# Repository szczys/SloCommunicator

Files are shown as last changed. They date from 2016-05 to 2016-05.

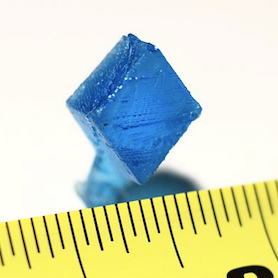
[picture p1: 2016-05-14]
board/peachy.png

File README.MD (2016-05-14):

SloCommunicator
======

Screen with Know and Home Etched Board

Communicator watch built for 2016 Bring-a-Hack (end of Bay Area Maker Faire Weekend).

This is based on the stalled [SloJak](https://github.com/szczys/SloJak) project. It is a 128x64 OLED screen with a rotary encoder and two buttons (actually 3 with encoder click but that's not designed into the board artwork).

Two things prevent this watch from communicating: I would need a second one to communicate with, and I didn't include the 900 MHz radio module in the design. This is just a quick and dirty built.

To make up for the lack of actual communications I will write KnobSnake, a classic game of snake that's played only by spinning the rotary encoder knob.

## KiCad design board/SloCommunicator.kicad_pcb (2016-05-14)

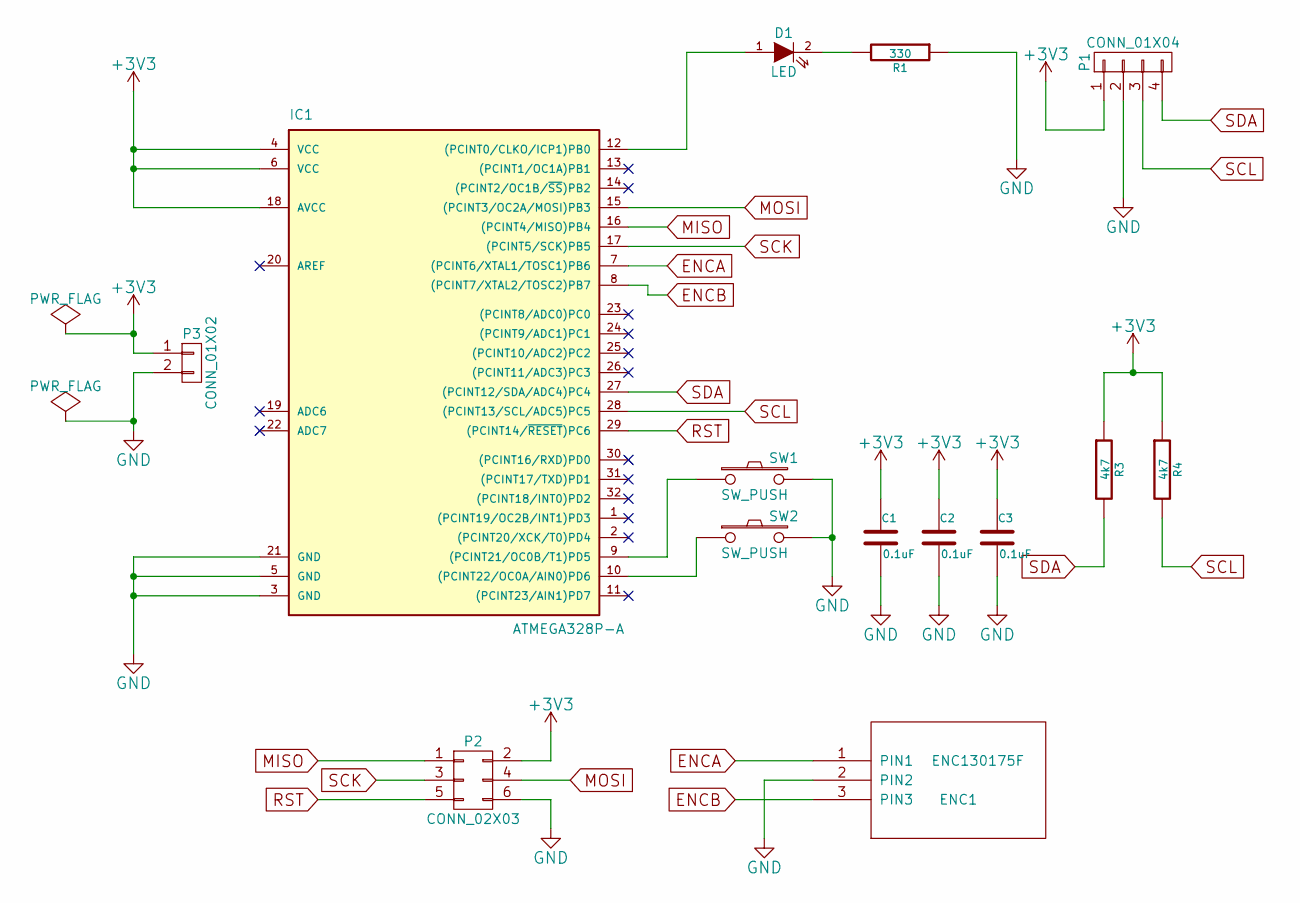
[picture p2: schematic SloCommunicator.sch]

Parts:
C1, C2, C3: 0.1uF; C_0805
D1: LED; LED_0805
ENC1: ENC130175F; enc130175f
IC1: ATMEGA328P-A; TQFP-32_7x7mm_Pitch0.8mm
P1: CONN_01X04; Pin_Header_Straight_1x04
P2: CONN_02X03; Pin_Header_Straight_2x03
P3: CONN_01X02; Pin_Header_Straight_1x02
R1: 330; R_0805
R3, R4: 4k7; R_0805
SW1, SW2: SW_PUSH; TACT_SMALL

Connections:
+3V3: C1.1, C2.1, C3.1, IC1.4 (VCC), IC1.6 (VCC), IC1.18 (AVCC), P1.1, P2.2, P3.1, R3.1, R4.1
ENCA: ENC1.1 (PIN1), IC1.7 ((PCINT6/XTAL1/TOSC1)PB6)
ENCB: ENC1.3 (PIN3), IC1.8 ((PCINT7/XTAL2/TOSC2)PB7)
GND: C1.2, C2.2, C3.2, ENC1.2 (PIN2), IC1.3 (GND), IC1.5 (GND), IC1.21 (GND), P1.2, P2.6, P3.2, R1.1, SW1.2, SW2.2
MISO: IC1.16 ((PCINT4/MISO)PB4), P2.1
MOSI: IC1.15 ((PCINT3/OC2A/MOSI)PB3), P2.4
unnamed: D1.1 (A), IC1.12 ((PCINT0/CLKO/ICP1)PB0)
unnamed: D1.2 (K), R1.2
unnamed: IC1.9 ((PCINT21/OC0B/T1)PD5), SW1.1
unnamed: IC1.10 ((PCINT22/OC0A/AIN0)PD6), SW2.1
RST: IC1.29 ((PCINT14/~RESET~)PC6), P2.5
SCK: IC1.17 ((PCINT5/SCK)PB5), P2.3
SCL: IC1.28 ((PCINT13/SCL/ADC5)PC5), P1.3, R4.2
SDA: IC1.27 ((PCINT12/SDA/ADC4)PC4), P1.4, R3.2

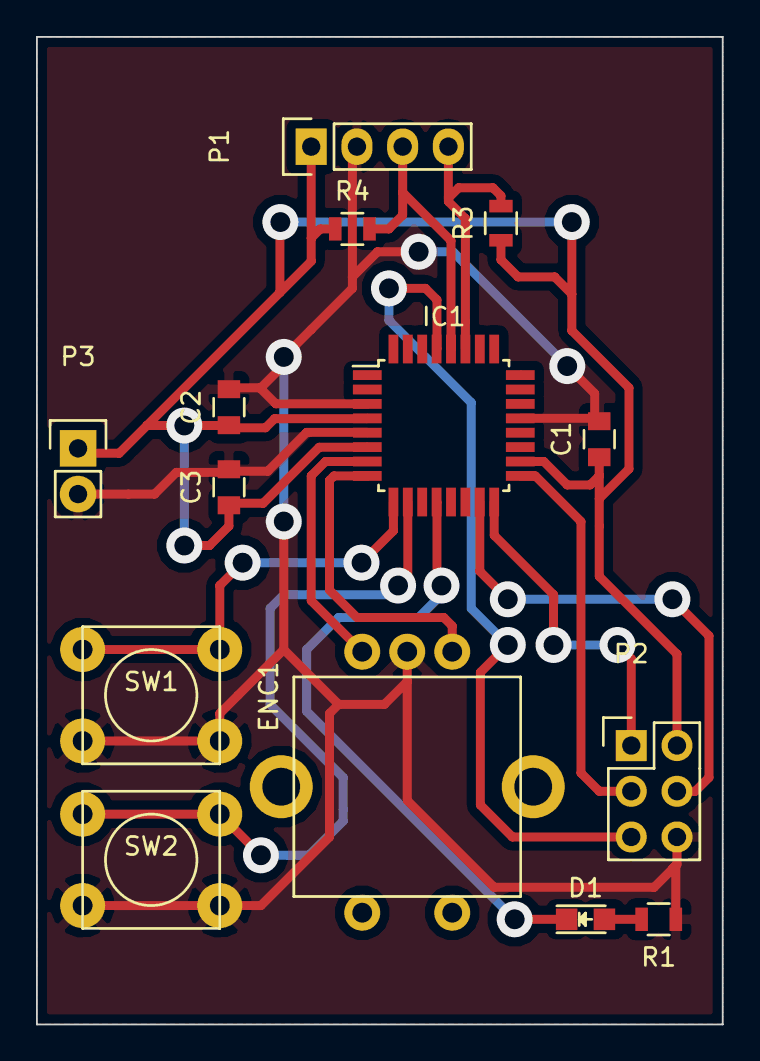
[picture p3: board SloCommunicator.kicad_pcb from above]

Board: 2 copper layers, 38.1 x 54.9 mm, 14 parts (0 on the bottom side), 14 nets.

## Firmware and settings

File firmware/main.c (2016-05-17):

/********************************
* SloJak                    	*
* MIT License               	*
* Copyright 2015 - Mike Szczys  *
* http://jumptuck.com 	    	*
*				                *
********************************/

#define F_CPU 8000000

#include <avr/io.h>
#include <avr/interrupt.h>
#include <avr/pgmspace.h>
#include <util/delay.h>

#include "menu.h"
#include "oledControl.h"
#include "game.h"


/************** Setup a rotary encoder ********************/
/* Atmega168 */
/* encoder port */
#define ENC_CTL	DDRB	//encoder port control
#define ENC_WR	PORTB	//encoder port write
#define ENC_RD	PINB	//encoder port read
#define ENC_A 6
#define ENC_B 7

volatile int8_t knobChange = 0;

/************** Setup input buttons *********************/
#define BUT_DDR     DDRD
#define BUT_PORT    PORTD
#define BUT_PIN     PIND
#define BUT_LEFT    (1<<PD5)
#define BUT_SEL     (1<<PD6)
#define BUT_MSK     (BUT_LEFT | BUT_SEL)

//Debounce
unsigned char debounce_cnt = 0;
volatile unsigned char key_press;
unsigned char key_state;

uint8_t goLeft = 0;
uint8_t goSel = 0;

uint8_t message[140] = "HELLOWORLDHELLOWORLDHELLOWORLDHELLOWORLDHELLOWORLDHELLOWORLDHELLOWORLD\0";

/**************** Prototypes *************************************/
unsigned char get_key_press(unsigned char key_mask);
void init_IO(void);
void init_interrupts(void);
int main(void);
/**************** End Prototypes *********************************/

/*********************
* Debounce Functions *
*********************/

unsigned char get_key_press(unsigned char key_mask)
{
  cli();               // read and clear atomic !
  key_mask &= key_press;                        // read key(s)
  key_press ^= key_mask;                        // clear key(s)
  sei();
  return key_mask;
}

void init_IO(void){
    //Rotary Encoder
    ENC_CTL &= ~(1<<ENC_A | 1<<ENC_B);
    ENC_WR |= 1<<ENC_A | 1<<ENC_B;

    //Buttons
    BUT_DDR &= ~(BUT_LEFT | BUT_SEL);      //Set as input
    BUT_PORT |= BUT_LEFT | BUT_SEL;      //Enable pull-up
}

void init_interrupts(void) {
    //Pin change interrupts for the rotary encoder
    PCICR |= 1<<PCIE0;      //enable PCINT0_vect  (PCINT0..7 pins)
    PCMSK0 |= 1<<PCINT6;    //interrupt on PCINT6 pin
    PCMSK0 |= 1<<PCINT7;    //interrupt on PCINT7 pin

    //Timer overflow for debounce and systick
    TCCR0B |= 1<<CS02 | 1<<CS00;		//Divide by 1024
    TIMSK0 |= 1<<TOIE0;			//enable timer overflow interrupt

    sei();
}

int main(void)
{
    init_IO();
    init_interrupts();
    oledInit();
    _delay_ms(200);

    oledSetCursor(cursX, cursY);
    putChar(66,1);
    advanceCursor(6);

    compose();

    initMenu();

    while(1)
    {
        if (get_key_press(BUT_SEL))
        {
            //Lookup and execute action
            doSelect[optionIndex]();
        }

        if (get_key_press(BUT_LEFT))
        {
            doBack();
        }

        if (knobChange) {
            if (knobChange > 0) {
                knobLeft();
            }
            else {
                knobRight();
            }
            knobChange = 0;
        }
        
        if (game_running && move_tick) {
            serviceGame();
            move_tick = 0;
        }
    }
}

ISR(PCINT0_vect) {
    /* Encoder service code is from Circuits@Home */
    /* https://www.circuitsathome.com/mcu/rotary-encoder-interrupt-service-routine-for-avr-micros */

    static uint8_t old_AB = 3;  //lookup table index
    static int8_t encval = 0;   //encoder value
    static const int8_t enc_states [] PROGMEM = {0,-1,1,0,1,0,0,-1,-1,0,0,1,0,1,-1,0};  //encoder lookup table

    old_AB <<=2;  //remember previous state
    old_AB |= ((ENC_RD>>6) & 0x03 ); //Shift magic to get PB6 and PB7 to LSB
    encval += pgm_read_byte(&(enc_states[( old_AB & 0x0f )]));
    /* post "Navigation forward/reverse" event */
    if( encval < -3 ) {  //four steps forward
        knobChange = -1;
        encval = 0;
    }
    else if( encval > 3  ) {  //four steps backwards
        knobChange = 1;
        encval = 0;
    }
}

ISR(TIMER0_OVF_vect) {
    static unsigned char ct0, ct1;
    unsigned char i;

    TCNT0 = (unsigned char)(signed short)-(F_CPU / 1024 * 10e-3 + 0.5);   // preload for 10ms

    i = key_state ^ ~BUT_PIN;    // key changed ?
    ct0 = ~( ct0 & i );          // reset or count ct0
    ct1 = ct0 ^ (ct1 & i);       // reset or count ct1
    i &= ct0 & ct1;              // count until roll over ?
    key_state ^= i;              // then toggle debounced state
    key_press |= key_state & i;  // 0->1: key press detect
    
    static uint8_t delayCount = STD_DELAY/10;   //This is a red herring. delayCount should be exposed to game.c
    
    if (++timingDelay >= delayCount) {
        timingDelay = 0;
        ++move_tick;
    }
}

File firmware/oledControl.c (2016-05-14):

#include "oledControl.h"
#include "font5x8.h"
#include <avr/pgmspace.h>

void oledInit(void) {
    cursX = 1;
    cursY = 0;

    i2c_init();

    oledWriteCmd(OLED_CMD_DISPLAY_OFF);
    oledWriteCmd(0xD5); //clkdiv
    oledWriteCmd(0x80);
    oledWriteCmd(0xA8); //multiplex
    oledWriteCmd(0x3F);
    oledWriteCmd(0xD3); //displayoffet
    oledWriteCmd(0x00);
    oledWriteCmd(0x40); //displayStartLine
    oledWriteCmd(0x8D);
    oledWriteCmd(0x14);
    oledWriteCmd(0x20);
    oledWriteCmd(PAGE_ADDRESSING);
    oledWriteCmd(0xA1); //segremap 0x01
    oledWriteCmd(0xC8); //comscandec
    oledWriteCmd(0xDA);
    oledWriteCmd(0x12);
    oledWriteCmd(0x81);
    oledWriteCmd(0xCF);
    oledWriteCmd(0xD9);
    oledWriteCmd(0xF1);
    oledWriteCmd(0xDB);
    oledWriteCmd(0x40);

    oledWriteCmd(0x26);

    oledWriteCmd(0x00);
    oledWriteCmd(0x05);
    oledWriteCmd(0x00);
    oledWriteCmd(0x07);

    oledWriteCmd(0x2F);
    //oledWriteCmd(0x2E);

    //oledWriteCmd(0x26);
    oledWriteCmd(OLED_CMD_DISPLAY_ON);
    oledWriteCmd(OLED_CMD_NORMAL_DISPLAY);

/*
    i2c_start_wait(OLED_ADDRESS);
    i2c_write(OLED_COMMAND_MODE);
    i2c_write(0x26);
    i2c_write(0x00);
    i2c_write(0x00);
    i2c_write(0x00);
    i2c_write(0x00);
    i2c_write(0x00);
    i2c_write(0xFF);
    i2c_stop();
*/
    oledClearScreen(1);
}

void oledWriteCmd(uint8_t cmd) {
    i2c_start_wait(OLED_ADDRESS+I2C_WRITE);
    i2c_write(OLED_COMMAND_MODE);
    i2c_write(cmd);
    i2c_stop();
}

void oledWriteData(uint8_t data) {
    i2c_start_wait(OLED_ADDRESS+I2C_WRITE);
    i2c_write(OLED_DATA_MODE);
    i2c_write(data);
    i2c_stop();
}

void oledSetCursor(uint8_t col, uint8_t page) {
    col += 2;   //Display off by 2 columns for some reason
    //Page
    oledWriteCmd(0xB0 + page);
    //Column
    oledWriteCmd(0x0F & col);
    oledWriteCmd(0x10 + (col>>4));
}

void oledClearScreen(uint8_t black) {
    uint8_t value = 0xFF;
    if (black) { value = 0x00; }
    for (uint8_t page=0; page<8; page++) {
        oledWriteCmd(0xB0 + page);
        oledWriteCmd(0x00);
        oledWriteCmd(0x10);
        i2c_stop();

        i2c_start_wait(OLED_ADDRESS);
        i2c_write(OLED_DATA_MODE);
        for (uint8_t col=0; col<128; col++) {
            oledWriteData(value);
        }
        i2c_stop();
    }
}

void putChar(uint8_t charIdx, uint8_t inverted) {
    uint8_t invertMask = 0x00;
    if (inverted) { invertMask = 0xFF; }
    for (uint8_t col = 0; col < 5; col++) {
        oledWriteData((getFont(charIdx,col))^invertMask);
    }
    oledWriteData(invertMask);    //Space after each letter
}

char getFont(uint8_t charIdx, uint8_t column)
{
    return pgm_read_byte(font5x8+((charIdx-32)*5)+column);
}

void putString(int16_t x, int16_t y, char *msg, uint8_t inverted) {
    const uint8_t charWidth = 6;
    const uint8_t charHeight = 1;

    //Find str length
    uint8_t i;
    for (i=0; i<141; i++) {
        if (msg[i] == 0) {
            if (i == 0) { return; } //zero len string
            else { break; }
        }
    }
    uint16_t colPosition;
    uint16_t rowPosition;
    for (uint8_t j=0; j<i; j++) {
        colPosition = x+(charWidth*j);
        rowPosition = y;

        //Linewrap
        if (colPosition+charWidth >= SCREENX) {
            uint8_t charPerRow = (SCREENX/charWidth);
            uint8_t charPos = j-((SCREENX-x)/charWidth);

            colPosition = (charPos%charPerRow)*charWidth;
            rowPosition = y+charHeight + (charHeight*(charPos/charPerRow));
        }
        oledSetCursor(colPosition, rowPosition);
        putChar(msg[j], inverted);
    }
}

void advanceCursor(uint8_t size) {
    cursX += size;
    if (cursX > SCREENX-size) {
        cursX = 0;
        if (++cursY >= SCREENY) { cursY = 0; }
    }
}

void showCharList(uint8_t startChar, uint8_t maxChar, uint8_t line) {
    for (uint8_t i=0; i<CHARPERLINE; i++) {
        if (startChar>=maxChar) { startChar = 0; }
        oledSetCursor((i*CHARWID)+1,line);  //adding 1 centers on a 128px screen with 6px CHARWID
        putChar(startChar+32, 0);
        startChar++;
    }
}

/*
Decrements index tracking which letter starts alphabet
startChar is first letter printed on line
maxChar is total number of chars in set
*/
uint8_t decCharIdx(uint8_t startChar, uint8_t maxChar)
{
    if (startChar == 0) { return maxChar-1; }
    return --startChar;
}

/*
Increments index tracking which letter starts alphabet
startChar is first letter printed on line
maxChar is total number of chars in set
*/
uint8_t incCharIdx(uint8_t startChar, uint8_t maxChar)
{
    if (startChar >= maxChar) { return 0; }
    return ++startChar;
}

void showHighlighted(uint8_t x, uint8_t y) {
    oledSetCursor(x,y);
    for (uint8_t i=0; i<5; i++) {
        oledWriteData(0b01000000);
    }
    oledWriteData(0x00);
}

/*
curStart = which char is first on the row
maxChar = total number of chars in set
returns: which char idx is highlighted onscreen
*/
uint8_t findHighlighted(uint8_t curStart, uint8_t maxChar) {
    //NOTE: beware overflows
    uint8_t newIdx = curStart+HIGHLIGHTCHAR;
    if (newIdx >= maxChar) { newIdx -= maxChar;}
    return newIdx;
}

uint8_t embiggen(uint8_t charSlice, uint8_t bottom) {
    if (bottom) { charSlice = charSlice>>4; }
    uint8_t returnByte = 0x00;
    for (uint8_t i=0; i<8; i++) {
    /*
        old new
        0   0
        0   1
        1   2
        1   3
        2   4
        2   5
        3   6
        3   7
    */
        if (charSlice & (1<<(i/2))) { returnByte |= (1<<i); }
    }
    return returnByte;
}

void putDblChar(uint8_t x, uint8_t y, uint8_t charIdx) {
    for (uint8_t row=0; row<2; row++) {
        for (uint8_t col = 0; col < 5; col++) {
            uint8_t embiggened = embiggen(getFont(charIdx,col),row);
            oledSetCursor(x+(2*col),y+row);
            oledWriteData(embiggened);
            oledWriteData(embiggened);
        }
        oledWriteData(0x00);    //Space after each letter
        oledWriteData(0x00);    //Space after each letter
    }
}

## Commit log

2016-05-14 Added button debounce; cleaned up
2016-05-14 Added game option Added ability to set pixel (FIXME ready byte locaiton from display first so we don't overwrite)
    [menu.c, oledControl.c]
